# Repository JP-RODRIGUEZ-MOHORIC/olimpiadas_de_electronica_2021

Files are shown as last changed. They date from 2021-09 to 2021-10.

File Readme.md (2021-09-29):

## _Olimpiadas de electronica 2021_

Este es un proyecto institucional realizado por los alumnos de la EEST N°5 de Temperley para las olimpiadas de electronica de 2021.
Integrantes:

- Alejo Perin
- Juan Pablo Rodriguez Mohoric
- Ivan Seifert
- Ramiro Sanchez
- Agustin Di Santo

## Proyecto 

El proyecto consta de un sistema de detección de CO2 para una habitación. Cuando se detecte un alto nivel del mismo se activará un mecanismo de ventilación para la extracción de este. El nivel de CO2 y otros datos podran ser vizualizados mediante una página web a la cual se ingresará con una contraseña a través de un teclado matricial para poder descargar un reporte de niveles de CO2 en función del tiempo.

## Tecnologias utilizadas

- C++ (Arduino)
- HTML
- CSS

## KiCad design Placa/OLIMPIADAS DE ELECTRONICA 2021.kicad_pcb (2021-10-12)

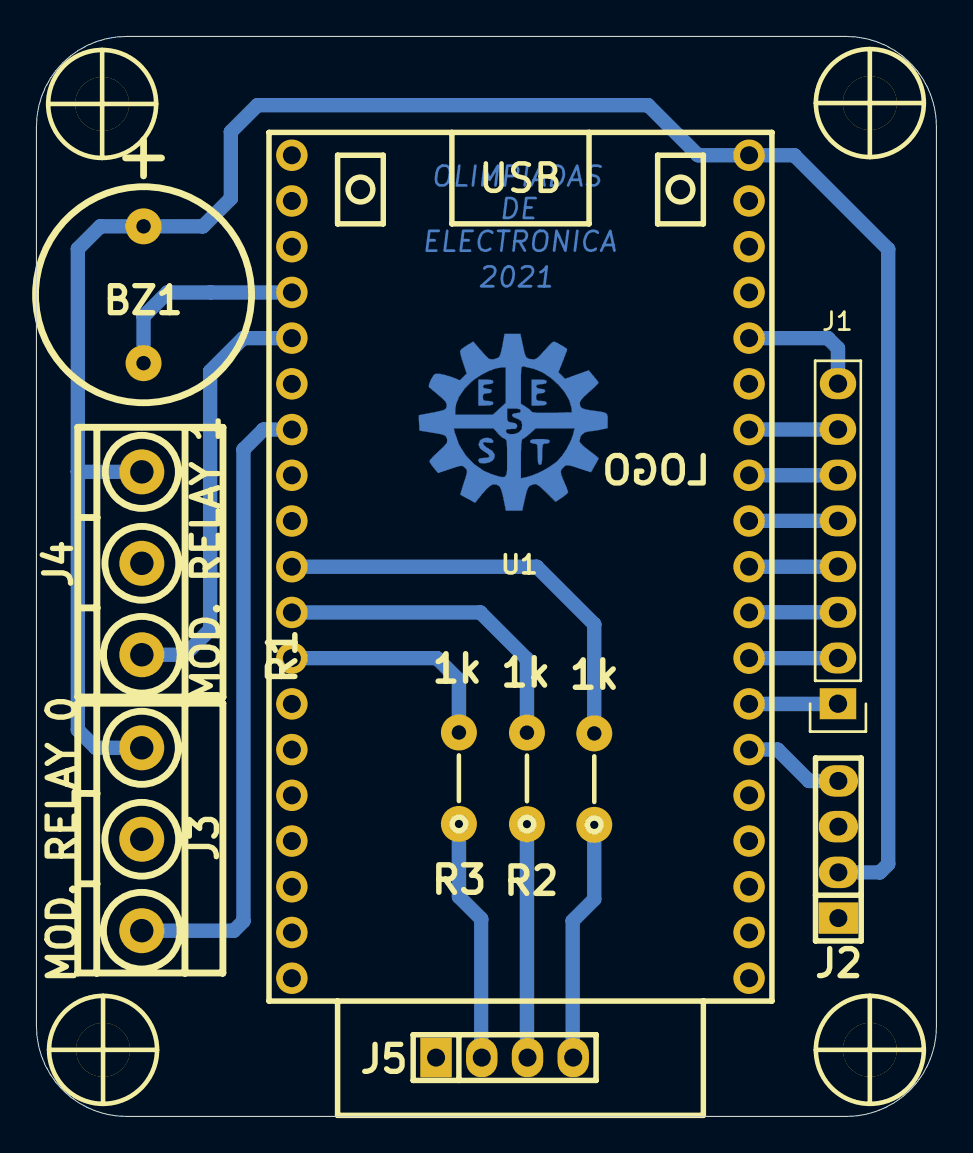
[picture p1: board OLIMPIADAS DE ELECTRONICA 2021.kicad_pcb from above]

Board: 2 copper layers, 50.0 x 60.0 mm, 14 parts (0 on the bottom side), 20 nets.

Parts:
BZ1: BUZZER; Buzzer_12mm
H1, H2, H3, H4: Mounting_Hole; hole_3mm
J1: TECLADO MATRICIAL; Pin_Header_Straight_1x08
J2: SENSOR CO2; pin_strip_4
J3: MOD. RELAY 0; BORNERA3_AZUL
J4: MOD. RELAY 1; BORNERA3_AZUL
J5: LED RGB; pin_strip_4
R1, R2, R3: 1k; RES0.2
U1: ESP32_DEVKITC

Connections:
/5V: BZ1.1, J2.2, J3.1, J4.1, U1.19
/GND: J2.1, J3.2, J4.2, J5.1, U1.32, U1.38
/PIN_2: J4.3, U1.24
/PIN_4: J3.3, U1.26
/PIN_5: R1.2, U1.29
/PIN_12: J1.7, U1.13
/PIN_13: J1.8, U1.15
/PIN_14: J1.6, U1.12
/PIN_15: BZ1.2, U1.23
/PIN_18: R2.2, U1.30
/PIN_19: R3.2, U1.31
/PIN_25: J1.3, U1.9
/PIN_26: J1.4, U1.10
/PIN_27: J1.5, U1.11
/PIN_32: J1.1, U1.7
/PIN_33: J1.2, U1.8
/PIN_35: J2.4, U1.6
unnamed: J5.2, R3.1
unnamed: J5.3, R2.1
unnamed: J5.4, R1.1

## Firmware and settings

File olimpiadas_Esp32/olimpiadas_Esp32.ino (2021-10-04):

#include <ESP32Time.h>   // Load Esp32 RTC libbrary
#include <analogWrite.h> // Load Esp32 analogwrite library
#include <Keypad.h>      // Load Keypad library
#include <WiFi.h>        // Load Wi-Fi library
#define DEBUG 0
#define CONECTION 1
#define PORT 80

// Replace with your network credentials
const char *ssid = "Leo mar juan";
const char *WiFi_password = "IVOM8264";

// Set web server port number to 80
WiFiServer server(PORT);

// Variable to store the HTTP request
String header;

// Current time
unsigned long currentTime = millis();
// Previous time
unsigned long previousTime = 0;
// Define timeout time in milliseconds (example: 2000ms = 2s)
const long timeoutTime = 2000;

//RTC
ESP32Time rtc;
String str_now;

//CO2 Sensor variables
#define THRSH 600      //750
#define THRSL 500      //500
#define THRS_ALARM 750 //900
#define MQ135 35
#define ON true
#define OFF false
int CO2_Status;
int CO2;
int CO2_final;
bool ventilation_status = false;
bool alarm_status = false;

//Finite-state Machine variables
#define STDBY 1
#define EXTRACCION 2
#define ALARM 3

//Motors
#define MOTOR_IN 2
#define MOTOR_OUT 4

//Buzzer
#define BUZZER 15

//RGB Led
#define PIN_RED 19
#define PIN_GREEN 18
#define PIN_BLUE 5

//Keypad variables
#define RESET 0
#define CORRECT 1
#define INCORRECT 2

const byte ROW = 4;        // Defines rows
const byte COLUMN = 4;     // Defines columns
char keys[ROW][COLUMN] = { // Defines keys distribution
    {'1', '2', '3', 'A'},
    {'4', '5', '6', 'B'},
    {'7', '8', '9', 'C'},
    {'*', '0', '#', 'D'}};

byte rowpins[ROW] = {13, 12, 14, 27};       // Row pins
byte columnpins[COLUMN] = {26, 25, 33, 32}; // Column pins

Keypad keypad = Keypad(makeKeymap(keys), rowpins, columnpins, ROW, COLUMN); // Creates an object

char key;         // Stores the pressed key
char password[7]; // Stores in an array the 6 keys pressed
int key_comprobation = 0;
char master_key_1[7] = "147147"; // Stores in an array the correct password 1
char master_key_2[7] = "369369"; // Stores in an array the correct password 2
char master_key_3[7] = "912018"; // Stores in an array the correct password 3
char master_key_4[7] = "266011"; // Stores in an array the correct password 4
char master_key_5[7] = "503282"; // Stores in an array the correct password 5
char master_key_6[7] = "123456"; // Stores in an array the correct password 6

int index_keypad = 0; // Array index

//Table structure
struct User
{
  int id;
  String entrance;
  int CO2_level;
  String system_status;
  bool login = false;
};

User user_1 = User();
User user_2 = User();
User user_3 = User();
User user_4 = User();
User user_5 = User();
User user_6 = User();

int Users_login_count = 0;
User sessions[20];

User GenerateUser(int id)
{
  User user = User();
  user.id = id;
  user.entrance = str_now;
  user.CO2_level = CO2_final;
  user.system_status = "OK";
  return user;
}

void setup()
{

  Serial.begin(115200);
  if (CONECTION)
  {
    //Connect to Wi-Fi network with SSID and password
    Serial.print("Connecting to ");
    Serial.println(ssid);
    WiFi.begin(ssid, WiFi_password);
    while (WiFi.status() != WL_CONNECTED)
    {
      delay(500);
      Serial.print(".");
    }

    //Print local IP address and start web server
    Serial.println("");
    Serial.println("WiFi connected.");
    Serial.println("IP address: ");
    Serial.println(WiFi.localIP());
    server.begin();
  }

  //Set RGB led pins as OUTPUTS
  pinMode(PIN_RED, OUTPUT);
  pinMode(PIN_GREEN, OUTPUT);
  pinMode(PIN_BLUE, OUTPUT);

  //Starts Finite-state machine
  green_led();
  CO2_Status = STDBY;

  //Set Motors as OUTPUTS
  pinMode(MOTOR_IN, OUTPUT);
  pinMode(MOTOR_OUT, OUTPUT);

  //Set buzzer pin as OUTPUT
  pinMode(BUZZER, OUTPUT);

  //Generate 6 users
  user_1 = GenerateUser(1);
  user_2 = GenerateUser(2);
  user_3 = GenerateUser(3);
  user_4 = GenerateUser(4);
  user_5 = GenerateUser(5);
  user_6 = GenerateUser(6);

  //Starts RTC
  RtcInit();
}

void loop()
{

  Rtc();
  Mef_CO2();
  KeypadRead();
  Server();
}

void RtcInit()
{
  String months[] = {"Jan", "Feb", "Mar", "Apr", "May", "Jun", "Jul", "Aug", "Sep", "Oct", "Nov", "Dec"};
  int mm = 1;

  int hh = String(__TIME__).substring(0, 2).toInt();
  int mn = String(__TIME__).substring(3, 5).toInt();
  int dd = String(__DATE__).substring(4, 6).toInt();
  String mm_aux = String(__DATE__).substring(0, 3);
  int yy = String(__DATE__).substring(7, 11).toInt();

  for (int x = 0; x < 12; x++)
  {
    if (months[x] == mm_aux)
    {
      mm = x + 1;
      break;
    }
  }
  rtc.setTime(00, mn, hh, dd, mm, yy); // (seconds, minutes, hours, days, months, years)
}

void Rtc()
{
  str_now = rtc.getTime("%d/%m/%Y %H:%M:%S ");
  Serial.println(str_now);
}

void LeerSensor()
{
  //Sensor code
  CO2 = analogRead(MQ135); //Read the sensor´s analogic pin
  CO2_final = map(CO2, 0, 4095, 0, 1023);
  float voltaje = CO2_final * (5.0 / 1023.0); //Gets the equivalent in volts
  if (DEBUG)
  {
    Serial.print("adc:");
    Serial.print(CO2_final);
    Serial.print("    voltaje:");
    Serial.println(voltaje);
  }
}

void Mef_CO2()
{
  LeerSensor();
  switch (CO2_Status)
  {
  case STDBY:
    if (CO2_final > THRSH)
    { 
      //Evaluates if CO2 level its over the limit
      Serial.println("Enciendo led Amarillo");
      CO2_Status = EXTRACCION;
      ventilation_status = ON;
      digitalWrite(MOTOR_IN, HIGH);
      digitalWrite(MOTOR_OUT, HIGH);
      yellow_led();
    }
    break;
  case EXTRACCION:
    if (CO2_final > THRS_ALARM)
    {
      Serial.println("Enciendo led rojo");
      CO2_Status = ALARM;
      alarm_status = ON;
      digitalWrite(BUZZER, HIGH);
      red_led();
    }

    if (CO2_final < THRSL)
    { 
      //Evaluates if CO2 level is lower than the limit and sets the FSM in STDBY mode. 
      Serial.println("Enciendo led Verde");
      CO2_Status = STDBY;
      ventilation_status = OFF;
      digitalWrite(MOTOR_IN, LOW);
      digitalWrite(MOTOR_OUT, LOW);
      green_led();
    }
    break;

  case ALARM:
    if (CO2_final < THRS_ALARM)
    {
      Serial.println("Enciendo led Amarillo");
      CO2_Status = EXTRACCION;
      alarm_status = OFF;
      digitalWrite(BUZZER, LOW);
      yellow_led();
    }
    break;
  }
}

void green_led()
{
  analogWrite(PIN_RED, 255);
  analogWrite(PIN_GREEN, 0);
  analogWrite(PIN_BLUE, 255);
}

void red_led()
{
  analogWrite(PIN_RED, 0);     
  analogWrite(PIN_GREEN, 255); 
  analogWrite(PIN_BLUE, 255);
}

void yellow_led()
{
  analogWrite(PIN_RED, 0); 
  analogWrite(PIN_GREEN, 207);
  analogWrite(PIN_BLUE, 255);
}

void KeypadRead()
{
  //keypad code
  key = keypad.getKey(); //Obtains the key pressed and asigns a variable
  if (key)               //Checks that a key was pressed
  {
    password[index_keypad] = key; //Stores in the array the key pressed
    index_keypad++;               //Increases the index + 1
    Serial.print(key);            //Sends to the serial monitor the key pressed
  }

  if (index_keypad == 6) //Evaluates if there are 6 keys stored
  {
    Autentification();
  }
  Logout();
}

void Autentification()
{
  if (!strcmp(password, master_key_1) or !strcmp(password, master_key_2) or !strcmp(password, master_key_3) or !strcmp(password, master_key_4) or !strcmp(password, master_key_5) or !strcmp(password, master_key_6))
  { //Compares the password whith the correct passwords

    Serial.print("Inicio de session:");
    Serial.println(Users_login_count);
    User session = User();

    if (!strcmp(password, master_key_1))
    {
      session = user_1;
    }
    if (!strcmp(password, master_key_2))
    {
      session = user_2;
    }
    if (!strcmp(password, master_key_3))
    {
      session = user_3;
    }
    if (!strcmp(password, master_key_4))
    {
      session = user_4;
    }
    if (!strcmp(password, master_key_5))
    {
      session = user_5;
    }
    if (!strcmp(password, master_key_6))
    {
      session = user_6;
    }
    session.login = true;
    session.CO2_level = CO2_final;
    session.entrance = str_now;
    sessions[Users_login_count] = session;
    Users_login_count++;
    index_keypad = 0;
    key_comprobation = CORRECT;
  }
  else
  {
    key_comprobation = INCORRECT;
  }
}

void Logout()
{
  if (key == 'A') //"A" Key restart the count and forces to type the password again
  {
    if (DEBUG)
    {
      Serial.println(" ");
      Serial.println("Ingresar Contraseña");
    }
    for (int x = 0; x < sizeof(password) / sizeof(password[0]); x++)
    {
      password[x] = 0;
    }
    key_comprobation = RESET;
    index_keypad = 0;
  }
}

void Server()
{
  //Server
  WiFiClient client = server.available(); //Listen for incoming clients

  if (client)
  { // //If a new client connects,
    currentTime = millis();
    previousTime = currentTime;
    //  Serial.println("New Client."); //print a message out in the serial port
    String currentLine = ""; //make a String to hold incoming data from the client
    while (client.connected() && currentTime - previousTime <= timeoutTime)
    { //loop while the client's connected
      currentTime = millis();
      if (client.available())
      {                         //if there's bytes to read from the client,
        char c = client.read(); //read a byte, then
        Serial.write(c);        //print it out the serial monitor
        header += c;
        if (c == '\n')
        { //if the byte is a newline character
          //if the current line is blank, you got two newline characters in a row.
          //that's the end of the client HTTP request, so send a response:
          if (currentLine.length() == 0)
          {

            HtmlHeaders(client);

            client.println(F("<html>"));
            client.println(F("<head>"));
            client.println(F("<meta charset='UTF-8'>"));
            client.println(F("<title>Panel de Control</title>"));
            WebRefresh(client);
            client.println(F("</head>"));
            client.println(F("<body onload='GetSwitchState()' id =  'switch_txt' style='background-color: #333; color: #fff;'>"));
            HtmlCo2View(client);
            client.println(F("<div style='display: flex; flex-direction: column; text-align: center; margin-right: auto; margin-left: auto; font-size: 25px; width: 100%; border-left: 2px solid white;  border-bottom: 2px solid white;'>"));
            HtmlClaveView(client);
            HtmlStatus(client, "Ventiladores", ventilation_status);
            HtmlStatus(client, "Alarma", alarm_status);
            client.println(F("</div>"));
            client.println(F("</div>"));

            if (key_comprobation == RESET)
            {
              client.println(F("<h1>Ingresar contraseña<h1>"));
            }

            //Table
            if (key_comprobation == CORRECT)
            {
              HtmlTableUsersSession(client);
              HtmlTableDownload(client);
            }

            if (key_comprobation == INCORRECT)
            {
              client.println(F("<h1>Contraseña Incorrecta<h1>"));
            }
            client.println(F("</body>"));
            client.println(F("</html>"));

            break;
          }
          else
          { //If you got a newline, then clear currentLine
            currentLine = "";
          }
        }
        else if (c != '\r')
        {                   //If you got anything else but a carriage return character,
          currentLine += c; //Add it to the end of the currentLine
        }
      }
    }
    //Clear the header variable
    header = "";
    //Close the connection
    client.stop();
    //Serial.println("Client disconnected.");
    //Serial.println("");
  }
}

void WebRefresh(WiFiClient client)
{
  client.println(F("<script>"));
  HtmlScriptDownloadTable(client);
  client.println(F("function GetSwitchState(){nocache = '&nocache=' + Math.random() * 1000000;"));
  client.println(F("var request = new XMLHttpRequest();"));
  client.println(F("request.onreadystatechange = function(){"));
  client.println(F("  if(this.readyState == 4){"));
  client.println(F("if(this.status == 200){"));
  client.println(F("if(this.responseText != null){"));
  client.println(F("document.getElementById('switch_txt').innerHTML = this.responseText;}}}}"));
  client.println(F("request.open('GET', 'ajax_switch' + nocache, true);"));
  client.println(F("request.send(null);"));
  client.println(F("setTimeout('GetSwitchState()', 1000);}"));

  client.println(F("</script>"));
}

void HtmlHeaders(WiFiClient client)
{
  // HTTP headers always start with a response code (e.g. HTTP/1.1 200 OK)
  // and a content-type so the client knows what's coming, then a blank line:
  client.println("HTTP/1.1 200 OK");
  client.println("Content-type:text/html");
  client.println("Connection: close");
  client.println();
  client.println();
}

void HtmlCo2View(WiFiClient client)
{
  client.println(F("<div style='display: flex; justify-content: space-between; height: 80vh;'>"));
  client.println(F("<div style='text-align: center; width: 40%; padding-top: 100px; border-bottom: 2px solid white;'>"));
  client.println(F("<p style='font-size: 40px; font-weight: bold;'>Sensor de CO2</p>"));
  client.println(F("<div style='display: inline-block; border: 2px solid black; border-radius: 10px; background-color: #fff; color: black;font-size: 50px;  width: 200px; height: 100px;'><p style='margin-top: 18px;'>"));
  client.println(CO2_final);
  client.println(F("</p></div>"));
  client.println(F("</div>"));
}

void HtmlClaveView(WiFiClient client)
{
  client.println(F("<div>"));
  client.println(F("<p>Contraseña</p>"));
  client.println(F("<p style='display: inline-block; border: 2px solid black; border-radius: 10px; background-color: #fff; color: black;padding: 5px; width: 100px; min-height: 25px;'>"));
  client.println(password);
  client.println(F("</p>"));
  client.println(F("</div>"));
}

void HtmlStatus(WiFiClient client, String title, bool sensor)
{
  String colorOn = "#00ff00";
  String colorOff = "#ff0000";
  client.println(F("<div>"));
  client.println(F("<p>"));
  client.print(title);
  client.println(F("</p>"));
  client.println(F("<p style='display: inline-block; border: 2px solid black; border-radius: 10px; padding: 5px; width:100px; color: white; background-color:"));
  client.print(sensor ? colorOn : colorOff);
  client.println(F(";'>"));
  client.print(sensor ? "on" : "off");
  client.println(F("</p>"));
  client.println(F("</div>"));
}

void HtmlTableUserRow(WiFiClient client, User user)
{
  client.println(F("<tr style='background-color: darkblue; text-align: center; font-size: 25px;'>"));
  client.println(F("<td>"));
  client.println(user.id);
  client.println(F("</td>"));
  client.println(F("<td>"));
  client.println(user.entrance);
  client.println(F("</td>"));
  client.println(F("<td>"));
  client.println(user.CO2_level);
  client.println(F("</td>"));
  client.println(F("<td>"));
  client.println(user.system_status);
  client.println(F("</td>"));
  client.println(F("</tr>"));
}

void HtmlTableUsersSession(WiFiClient client)
{

  client.print(F(
      "    <h1>Contraseña Correcta, Bienvenido</h1>"
      "    <h1 style='text-align: center'>Panel de Control</h1>"
      "    <div id='table_element'>"
      "      <table"
      "        style='"
      "          margin: auto;"
      "          margin-top: 10px;"
      "          background-color: #fff;"
      "          text-align: center;"
      "          height: 500px;"
      "          width: 900px;"
      "          border: 2px solid #fff;"
      "          border-top: none;"
      "        '"
      "      >"
      "        <caption"
      "          style='"
      "            background-color: darkblue;"
      "            text-align: center;"
      "            font-size: 25px;"
      "            border: solid 4px #fff;"
      "            border-bottom: none;"
      "          '"
      "        >"
      "          Tabla de Datos"
      "        </caption>"
      "        <thead"
      "          style='"
      "            background-color: darkblue;"
      "            text-align: center;"
      "            font-size: 25px;"
      "          '"
      "        >"
      "          <th>ID</th>"
      "          <th>Ingreso</th>"
      "          <th>Nivel Co2</th>"
      "          <th>Estado del sistema</th>"
      "        </thead>"
      "        <tbody style='text-align: center'>"));
  for (User session : sessions)
  {
    //Si existe usuarios logeados. Muestro su informacion en la table.
    if (session.login)
    {
      HtmlTableUserRow(client, session);
    }
  }
  client.print(F("</tbody>"
                 "      </table>"
                 "    </div>"));
}

void HtmlScriptDownloadTable(WiFiClient client)
{
  client.println(F(
      "function downloadTable(){"
      "   const tableElement = document.getElementById('table_element').innerHTML;"
      "   const bodyElement = document.body.innerHTML;"
      "   document.body.innerHTML = tableElement;"
      "   window.print();"
      "   document.body.innerHTML = bodyElement;"
      "}"));
}

void HtmlTableDownload(WiFiClient client)
{
  client.println(F(
      "<a"
      "  onclick='downloadTable()'"
      "  style='"
      "    width: 50px;"
      "    height: 50px;"
      "    margin-left: 290px;"
      "    font-size: 30px;"
      "    color: #fff;"
      "    cursor: pointer;"
      "  '>"
      "  Descargar datos de la tabla"
      "</a>"));
}

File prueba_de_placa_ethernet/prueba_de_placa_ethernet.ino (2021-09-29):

#include <SPI.h>
#include <Ethernet.h>
#include <Keypad.h>     // importa libreria Keypad

#define DEBUG 0

byte mac[] = { 0xDE, 0xAD, 0xBE, 0xEF, 0xFE, 0xED };
IPAddress ip(192, 168, 10, 177);
EthernetServer server(80);

//Variables del sensor de CO2
int CO2;
int mq135 = A0;
bool ventilacion;
#define CO2_LIMITE 500

//variables del keypad

const byte FILAS = 4;     // define numero de filas
const byte COLUMNAS = 4;    // define numero de columnas
char keys[FILAS][COLUMNAS] = {    // define la distribucion de teclas
  {'1','2','3','A'},
  {'4','5','6','B'},
  {'7','8','9','C'},
  {'*','0','#','D'}
};

byte pinesFilas[FILAS] = {9,8,7,6};   // pines correspondientes a las filas
byte pinesColumnas[COLUMNAS] = {5,4,3,2}; // pines correspondientes a las columnas

Keypad teclado = Keypad(makeKeymap(keys), pinesFilas, pinesColumnas, FILAS, COLUMNAS);  // crea objeto

char TECLA;       // almacena la tecla presionada
char CLAVE[7];        // almacena en un array 6 digitos ingresados
int comprobacion_clave = 0;

char CLAVE_MAESTRA_1[7] = "147147";   // almacena en un array la contraseña maestra
char CLAVE_MAESTRA_2[7] = "123456";
char CLAVE_MAESTRA_3[7] = "123456";
char CLAVE_MAESTRA_4[7] = "123456";
char CLAVE_MAESTRA_5[7] = "123456";
char CLAVE_MAESTRA_6[7] = "123456";

byte INDICE = 0;      // indice del array

//Estrusctura de datos
struct ingresantes{
  int id;
  char usuario[20];
  unsigned long int hora-ingreso;
  unsigned long int hora-egreso;
  char habitacion[20];
  int estado-sistema;
  int estado-bus;
} tabla[6];

void setup()
{
  Serial.begin(9600);

  Ethernet.begin(mac, ip);
  server.begin();

   if(DEBUG){
  Serial.print("server is at ");
  Serial.println(Ethernet.localIP());
   }
}

void loop()
{
  //Codigo deteccion del sensor
  CO2 = analogRead(mq135); //Lemos la salida analógica del MQ
  float voltaje = CO2 * (5.0 / 1023.0); //Convertimos la lectura en un valor de voltaje
  if(DEBUG){
  Serial.print("adc:");
  Serial.print(CO2);
  Serial.print("    voltaje:");
  Serial.println(voltaje);
  delay(1000);
  }
  
//  if(CO2 >= 500){
//    ventilacion = 1;
//  }else if(CO2 < 500){
//    ventilacion = 0;
//  }

   ventilacion = CO2 >= CO2_LIMITE; //si la condición es verdadera, el resultado de ventilacion será true, caso contrario false.
  
  if(DEBUG){
  Serial.println(ventilacion);
  }
  
  //codigo keypad
  TECLA = teclado.getKey();   // obtiene tecla presionada y asigna a variable
  if (TECLA)        // comprueba que se haya presionado una tecla
  {
    CLAVE[INDICE] = TECLA;    // almacena en array la tecla presionada
    INDICE++;       // incrementa indice en uno
    Serial.print(TECLA);    // envia a monitor serial la tecla presionada
  }

  if(INDICE == 6)       // si ya se almacenaron los 6 digitos
  {
    if(!strcmp(CLAVE, CLAVE_MAESTRA_1)){   // compara clave ingresada con clave maestra
      Serial.println(" Correcta"); // imprime en monitor serial que es correcta la clave
      comprobacion_clave = 1;}
    else{
      Serial.println(" Incorrecta");  // imprime en monitor serial que es incorrecta la clave
      comprobacion_clave = 2;
    }
  }
  if(TECLA == 'A'){
      Serial.println(" ");
      Serial.println("Ingresar Contraseña");
      for (int x = 0; x < sizeof(CLAVE) / sizeof(CLAVE[0]); x++)
      {
        CLAVE[x] = 0;
      }
      comprobacion_clave = 0;
      INDICE = 0;
      }
  
  
  EthernetClient client = server.available();
  if (client)
  {
    Serial.println("new client");
    bool currentLineIsBlank = true;
    String cadena = "";
    while (client.connected()) 
    {
      if (client.available()) 
      {
        char c = client.read();
        Serial.write(c);
        
        // Al recibir linea en blanco, servir página a cliente
        if (c == '\n' && currentLineIsBlank)
        {
          client.println(F("HTTP/1.1 200 OK\nContent-Type: text/html"));
          client.println("Conenection: close");
      
          //client.println(F("Refresh:0")); //Refresca la pagina automaticamente cada x tiempo
          String box_css = "display: inline-block; border: 2px solid black; border-radius: 10px; background-color: #fff; color: black;"
          String table_css = "background-color: darkblue; text-align: center; font-size: 25px;"
          client.println();
          client.println(F("<html>"));
          client.println(F("<head>"));
          client.println(F("<meta charset='UTF-8'>"));
          client.println(F("<title>Panel de Control</title>"));
          client.println(F("</head>"));
          client.println(F("<body style='background-color: #333; color: #fff;'>"));
          client.println(F("<div style='display: flex; justify-content: space-between; height: 80vh;'>"));
          client.println(F("<div style='text-align: center; width: 40%; padding-top: 100px; border-bottom: 2px solid white;'>"));
          client.println(F("<p style='font-size: 40px; font-weight: bold;'>Sensor de CO2</p>"));
          client.println(F("<div style='"+box_css+"font-size: 50px;  width: 200px; height: 100px;'><p style='margin-top: 18px;'>"));
          client.println(CO2);
          client.println(F("</p></div>"));
          client.println(F("</div>"));
          client.println(F("<div style='display: flex; flex-direction: column; text-align: center; margin-right: auto; margin-left: auto; font-size: 25px; width: 100%; border-left: 2px solid white;  border-bottom: 2px solid white;'>"));
          client.println(F("<div>"));
          client.println(F("<p>Contraseña</p>"));
          client.println(F("<p style='"+box_css+"padding: 5px; width: 100px; min-height: 25px;'>"));
          client.println(CLAVE);
          client.println(F("</p>"));
          client.println(F("</div>"));
          client.println(F("<div>"));
          client.println(F("<p>Datos 2</p>"));
          client.println(F("<p style='+"box_css+"padding: 5px; width: 100px;'>-</p>"));
          client.println(F("</div>"));
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

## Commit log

2021-10-03 Esp32 code added
2021-10-04 sensor pin changed to 35
2021-10-12 Scheme and PCB files added
    [OLIMPIADAS DE ELECTRONICA 2021.kicad_pcb, OLIMPIADAS DE ELECTRONICA 2021.sch]
